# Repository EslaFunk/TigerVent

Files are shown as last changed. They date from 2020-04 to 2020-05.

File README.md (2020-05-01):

# TigerVent #
## A Ventilator design inspired by Rice University's ApolloBMV with added Alarming and Pressure Sensing

Custom Enhancements from base ApolloBMV Design:
* Honeywell NSCDRRN001PDUNV Pressure Sensor integrated with driver (still available pressure sensor)
* Assist control mode that triggers the ventilator when negative pressure (a breath) is initiated
* Alarm/Buzzer and code to handle alarms based on pressure (WIP)
* Schematic and Board files for printed circuit board designed in EAGLE (confirmed tested and working)
* updated CAD file of chassis to fit PCB and CAD file of PCB
* alternate LCD driver implementation for more available 2004 LCD Screen
* Powershell script to automate updating library in seperate folder while also maintaining git capability

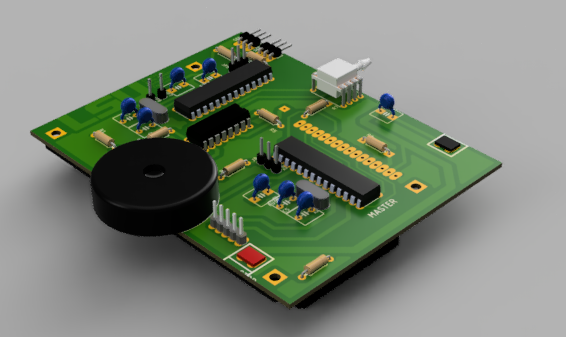
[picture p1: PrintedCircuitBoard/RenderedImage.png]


WARNING: This product is not yet approved by any regulatory agency. Please consult with a medical professional prior to use, and use at your own risk.

Special thanks to the team at Rice University for the base design. Hopefully these enhancements can provide more functionality and safety to others looking to implement these ventilators.

[renderedpcb]: https://github.com/kebroad/TigerVent/blob/master/PrintedCircuitBoard/RenderedImage.png

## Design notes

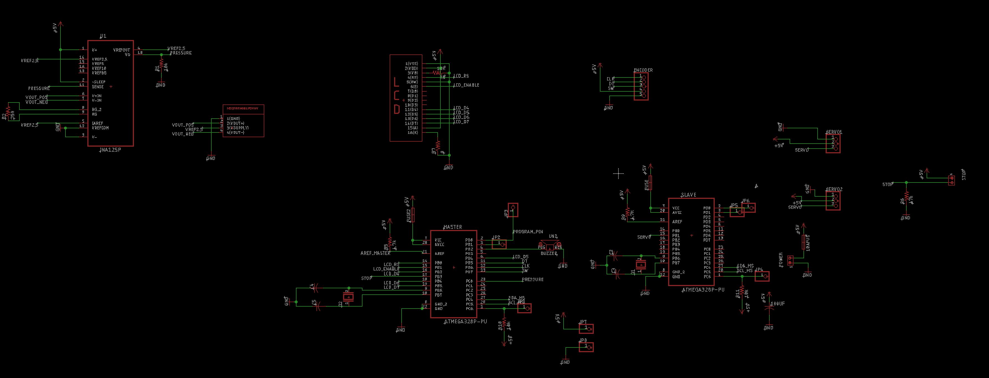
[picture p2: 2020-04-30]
PrintedCircuitBoard/schematic.jpg

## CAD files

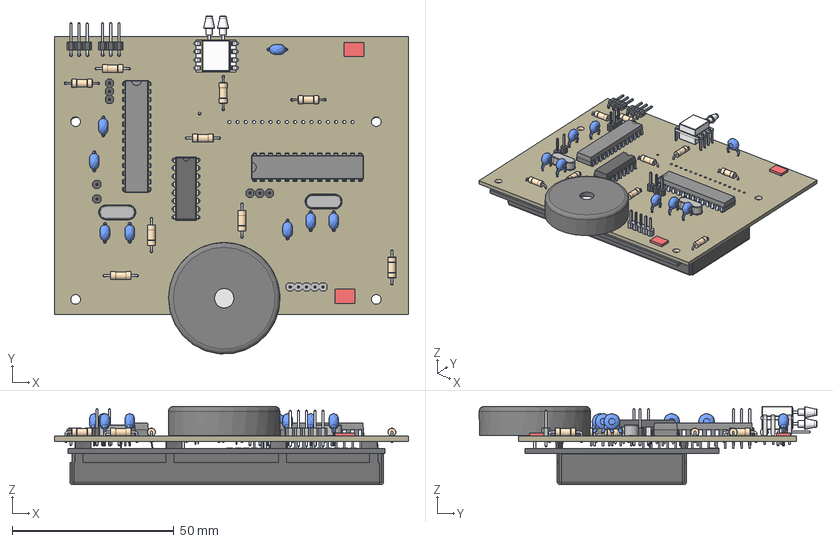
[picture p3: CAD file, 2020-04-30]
PrintedCircuitBoard/PCB.step
109.5 x 104.4 x 24.2 mm
Board
C050-075X075 x 8
ATMEGA328P-PU x 2
QS x 2
LCD
BUZZER
1X05
INA125P
4.7k x 9
1X03/90 x 2
1X01 x 8
DIP8-WIDE
1X2MTA x 2

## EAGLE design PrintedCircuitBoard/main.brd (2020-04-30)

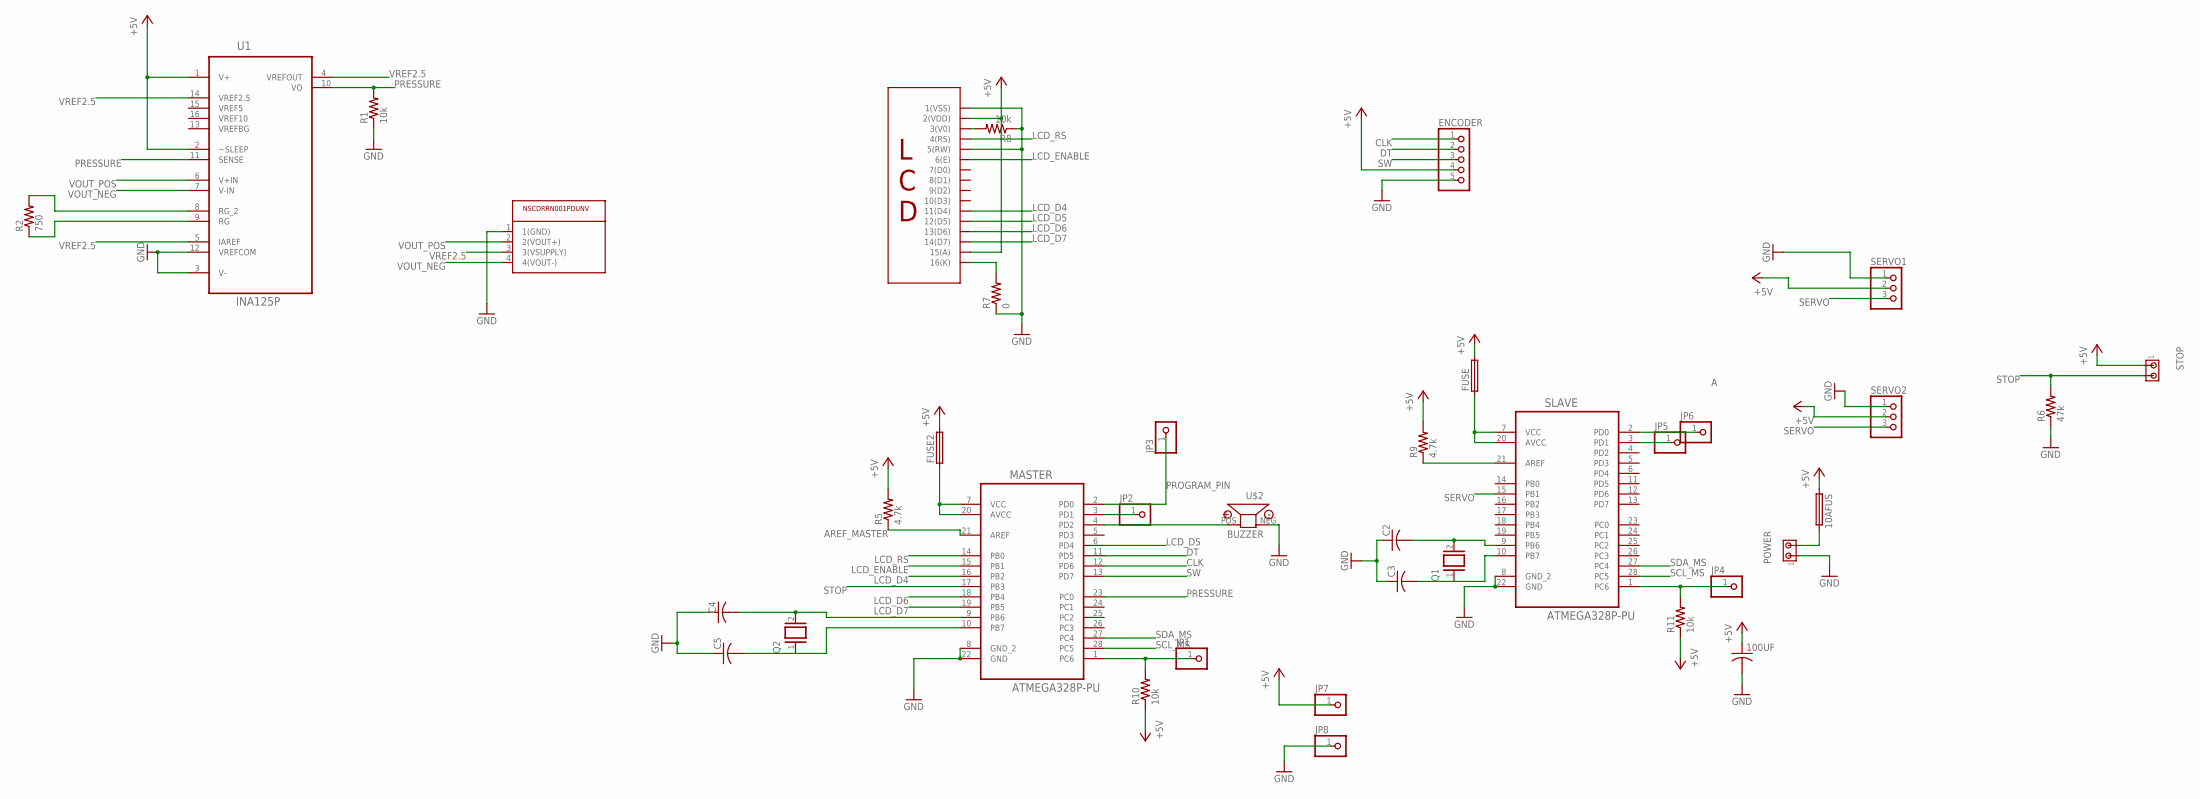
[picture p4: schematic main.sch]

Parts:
10AFUS: FUSE050-075X075; C050-075X075
100UF: 5MM_CAPACITOR050-075X075; C050-075X075
C2, C3, C4, C5: 5MM_CAPACITOR050-075X075; C050-075X075
ENCODER: PINHD-1X5; 1X05
FUSE, FUSE2: FUSE050-075X075; C050-075X075
JP1, JP2, JP3, JP4, JP5, JP6, JP7, JP8: PINHD-1X1; 1X01
MASTER: ATMEGA328P-PU; DIP254P762X457-28
POWER: MTA02-156; 1X2MTA
Q1, Q2: XTAL/S; QS
R1, R8, R10, R11: 10k; 0207/10
R2: 750; 0207/10
R5, R9: 4.7k; 0207/10
R6: 47k; 0207/10
R7: 0; 0207/10
SERVO1, SERVO2: PINHD-1X3/90; 1X03/90
SLAVE: ATMEGA328P-PU; DIP254P762X457-28
STOP: MTA02-156; 1X2MTA
U1: INA125P; DIP254P762X508-16
U$1: LCD; 1X16
U$2: BUZZER
U$3: PRESSURE_SENSOR; DIP8-WIDE

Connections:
+5V: 10AFUS.1, 100UF.1, ENCODER.4, FUSE.2, FUSE2.2, JP7.1, R5.2, R9.2, R10.1, R11.1, SERVO1.2, SERVO2.2, STOP.1, U1.1 (V+), U1.2 (~SLEEP), U$1.2 (2(VDD)), U$1.15 (15(A))
A: JP6.1, SLAVE.2 (PD0)
AREF_MASTER: MASTER.21 (AREF), R5.1
CLK: ENCODER.1, MASTER.12 (PD6)
DT: ENCODER.2, MASTER.11 (PD5)
GND: 100UF.2, C2.1, C3.1, C4.1, C5.1, ENCODER.5, JP8.1, MASTER.8 (GND_2), MASTER.22 (GND), POWER.1, R1.1, R6.1, R7.1, R8.1, SERVO1.1, SERVO2.1, SLAVE.8 (GND_2), SLAVE.22 (GND), U1.3 (V-), U1.12 (VREFCOM), U$1.1 (1(VSS)), U$1.5 (5(RW)), U$2.NEG, U$3.1 (1(GND))
LCD_D4: MASTER.16 (PB2), U$1.11 (11(D4))
LCD_D5: MASTER.6 (PD4), U$1.12 (12(D5))
LCD_D6: MASTER.18 (PB4), U$1.13 (13(D6))
LCD_D7: MASTER.19 (PB5), U$1.14 (14(D7))
LCD_ENABLE: MASTER.15 (PB1), U$1.6 (6(E))
LCD_RS: MASTER.14 (PB0), U$1.4 (4(RS))
unnamed: JP2.1, MASTER.3 (PD1)
unnamed: FUSE2.1, MASTER.7 (VCC), MASTER.20 (AVCC)
unnamed: FUSE.1, SLAVE.7 (VCC), SLAVE.20 (AVCC)
unnamed: 10AFUS.2, POWER.2
unnamed: R2.2, U1.8 (RG_2)
unnamed: C2.2, Q1.2, SLAVE.9 (PB6)
unnamed: C3.2, Q1.1, SLAVE.10 (PB7)
unnamed: JP1.1, MASTER.1 (PC6), R10.2
unnamed: JP4.1, R11.2, SLAVE.1 (PC6)
unnamed: C4.2, MASTER.9 (PB6), Q2.2
unnamed: JP5.1, SLAVE.3 (PD1)
unnamed: MASTER.4 (PD2), U$2.POS
unnamed: C5.2, MASTER.10 (PB7), Q2.1
unnamed: R7.2, U$1.16 (16(K))
unnamed: R8.2, U$1.3 (3(V0))
unnamed: R2.1, U1.9 (RG)
unnamed: R9.1, SLAVE.21 (AREF)
PRESSURE: MASTER.23 (PC0), R1.2, U1.10 (VO), U1.11 (SENSE)
PROGRAM_PIN: JP3.1, MASTER.2 (PD0)
SCL_MS: MASTER.28 (PC5), SLAVE.28 (PC5)
SDA_MS: MASTER.27 (PC4), SLAVE.27 (PC4)
SERVO: SERVO1.3, SERVO2.3, SLAVE.15 (PB1)
STOP: MASTER.17 (PB3), R6.2, STOP.2
SW: ENCODER.3, MASTER.13 (PD7)
VOUT_NEG: U1.7 (V-IN), U$3.4 (4(VOUT-))
VOUT_POS: U1.6 (V+IN), U$3.2 (2(VOUT+))
VREF2.5: U1.4 (VREFOUT), U1.5 (IAREF), U1.14 (VREF2.5), U$3.3 (3(VSUPPLY))
VREF5: U1.15 (VREF5)
VREF10: U1.16 (VREF10)
VREFBG: U1.13 (VREFBG)

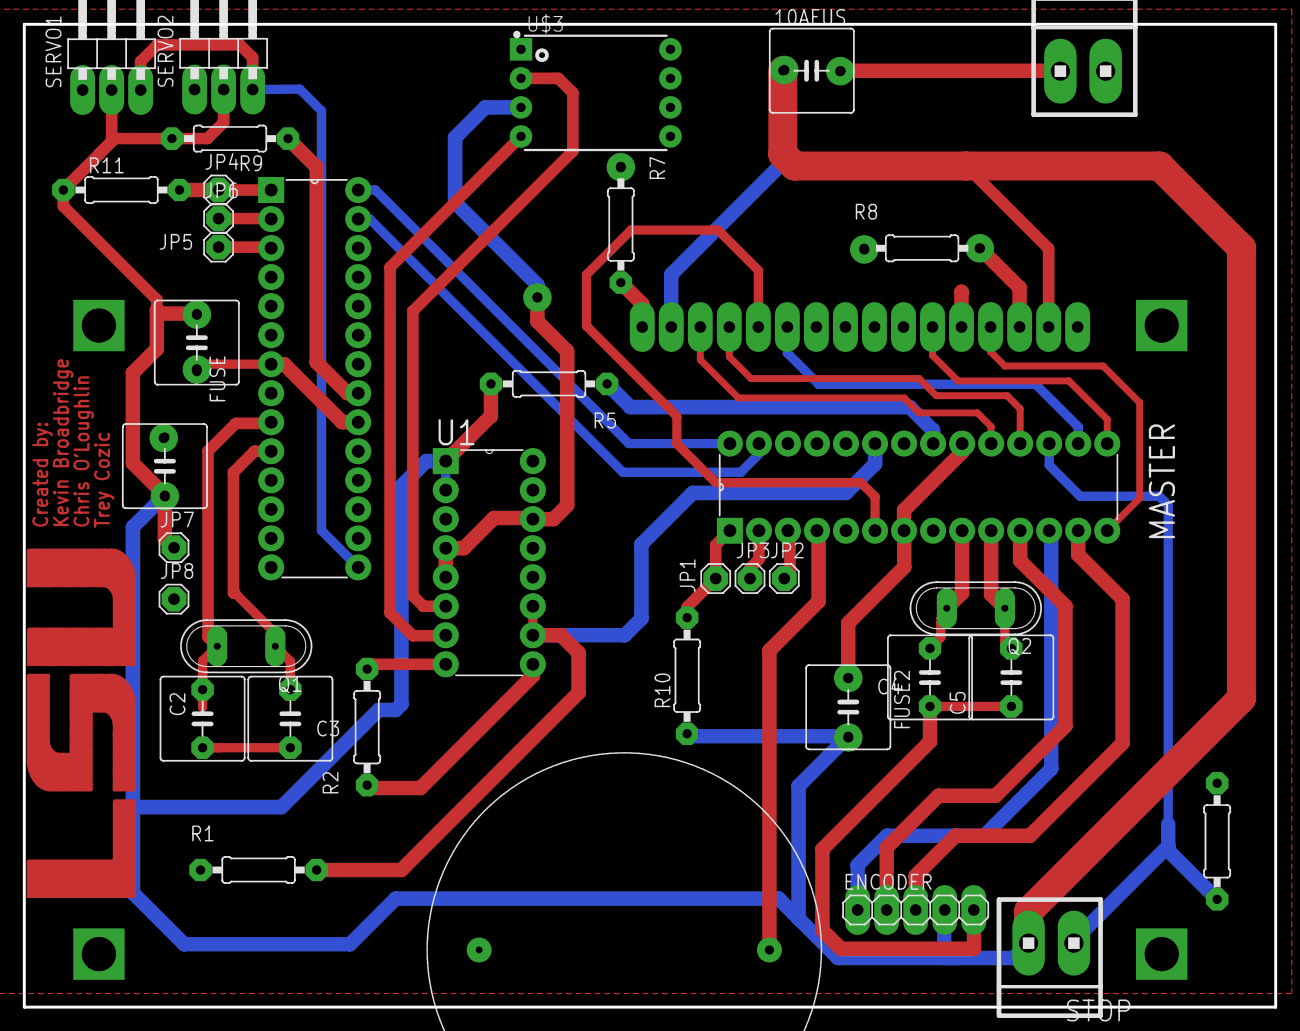
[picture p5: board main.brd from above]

Board: 2 copper layers, 109.5 x 86.0 mm, 38 parts (1 on the bottom side), 39 nets.

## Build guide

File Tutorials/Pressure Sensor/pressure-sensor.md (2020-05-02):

### Pressure Sensor:

For our pressure sensor, we decided to get the Honeywell NSCDRRN001PDUNV. This pressure sensor has a +-1 PSI range, which is +-70.307cm H2O. This is within range of the generally accepted maximum allowed 40 cm H20. This is a differential pressure sensor with two pressure inputs. The top port (port 1) is connected to the Ambu bag, and the bottom port (port 2) is left open to the atmosphere. This allows for the pressure to always be consistent. 

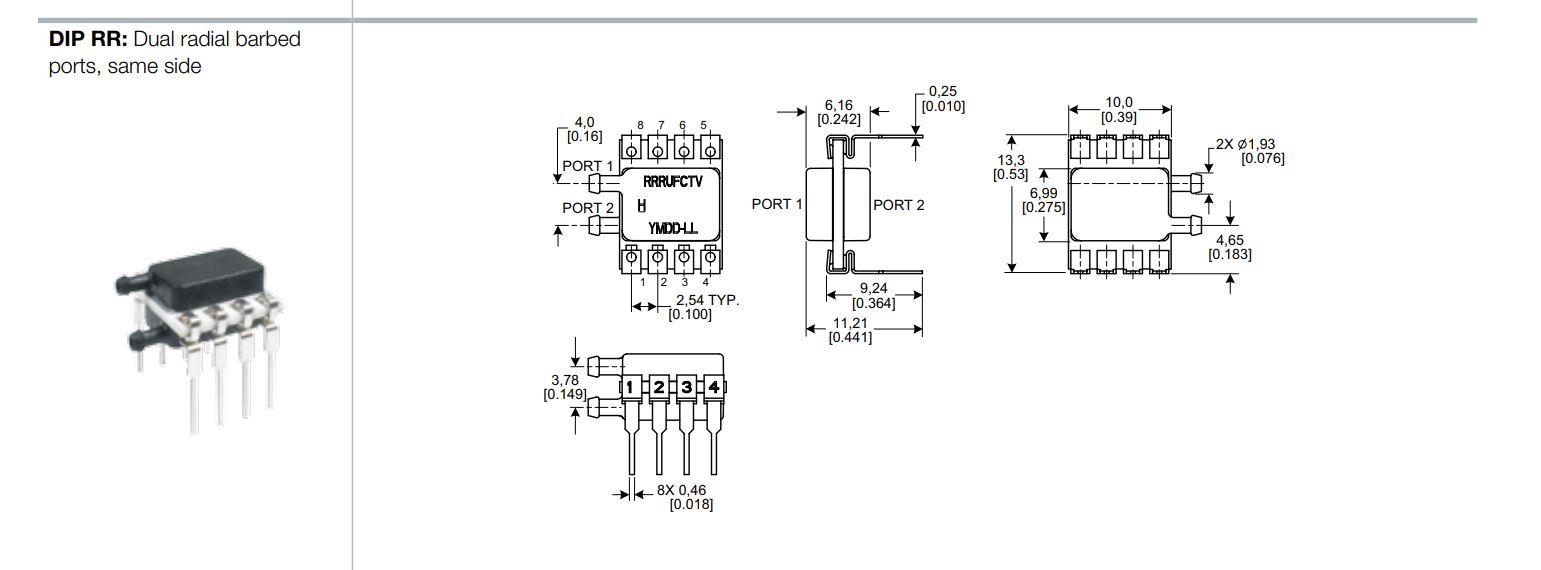
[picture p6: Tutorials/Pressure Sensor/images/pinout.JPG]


The pressure sensor part was created and is available in our eagle PCB library.

Here is our plumbing connection configuration:



We want the microcontroller to see the difference in pressure, or **Pressure Port 1 - Pressure Port 2**. This pressure sensor is an **unamplified** sensor, and has a range of about ~65mV. In order to provide an input of ~0-5V analog voltage to the microcontroller, we had to both amplify the signal while keeping the negative half of the range. We used the INA125 from TI to amplify the change in signal while maintaining its ~0-5V range by using the "psuedoground" of the 2.5V. Note that our actual circuit schematic differs slightly from this application circuit from the IINA125 datasheet.
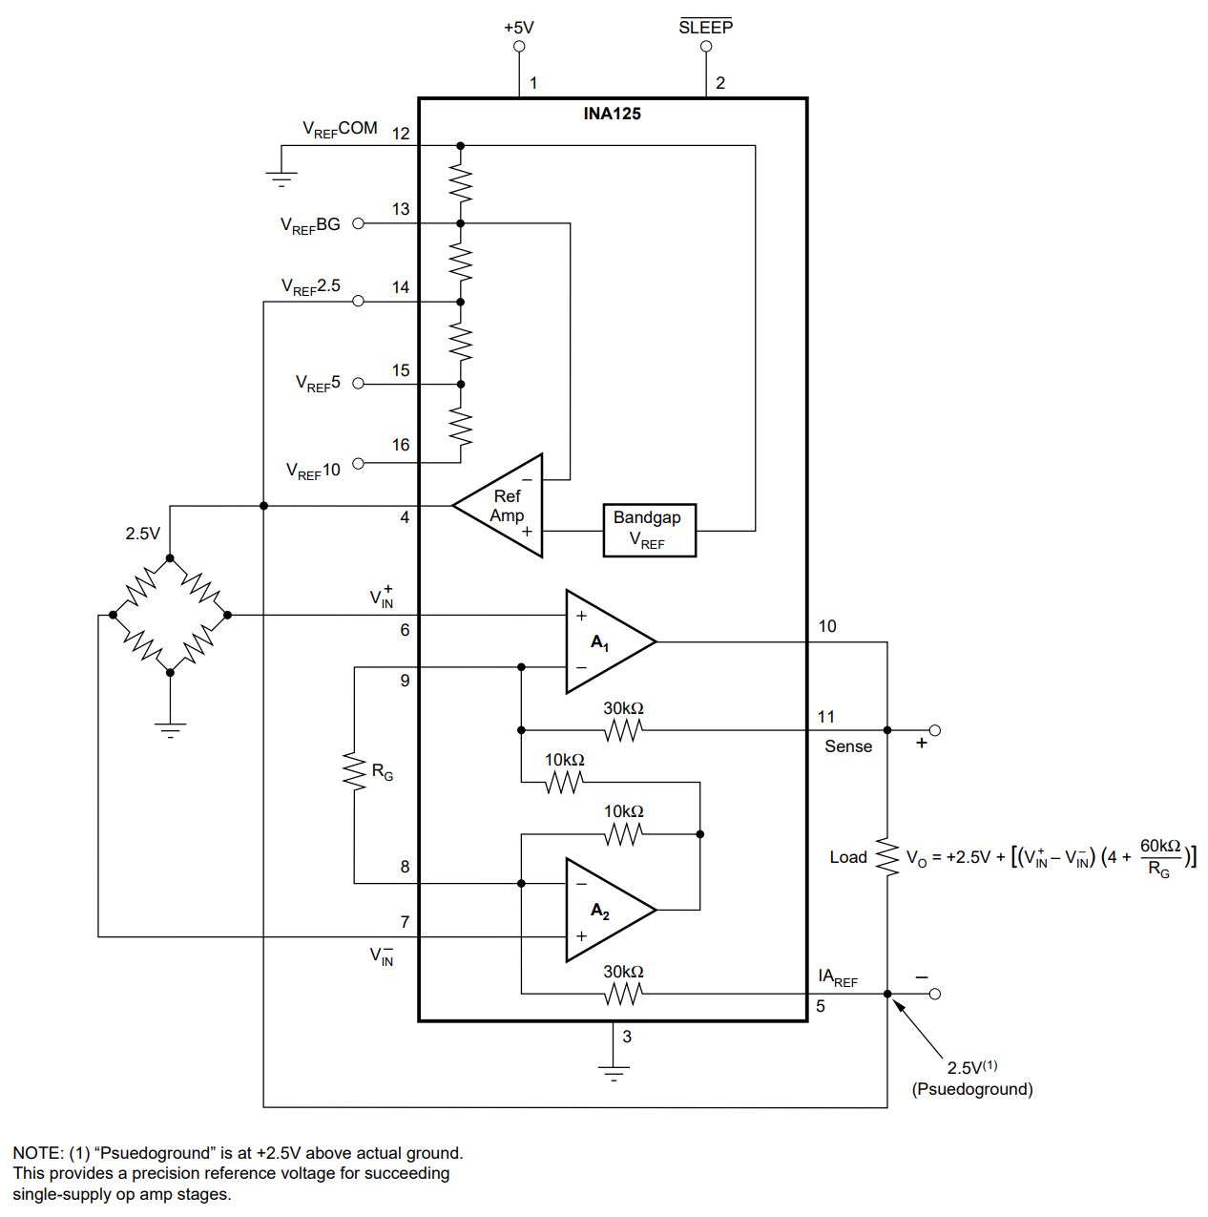
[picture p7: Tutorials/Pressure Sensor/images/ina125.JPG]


From the gain measurements and equation, we decided on a gain resistor (Rg) to be 750 Ohms. We were able to get a voltage range of ~0-4V from this configuration, going into the microcontroller, where ~2V is where both pressure ports have the same pressure.

In the code, we were able to adjust the voltage to cm H20 by finding the multiplier and constant (Pressure (cm H2O) = multiplier * Input (V) + Constant) and got the multiplier by the max/min in pressure range (|+-1| = 2 PSI or |+-70.307| = 140.614 cmH2O) over the max/min in the voltage range (~4V - 0 V) and, once getting the multiplier, got the constant offset by substituting one of the ends of the range into the equation. You will need to tweak these values based on the gain resistor you use and comparison with a pre-calibrated pressure sensor system.

[pinout]: https://github.com/kebroad/TigerVent/blob/master/Tutorials/Pressure%20Sensor/images/pinout.JPG

[plumbingconfig]: https://github.com/kebroad/TigerVent/blob/master/Tutorials/Pressure%20Sensor/images/plumbingconfig.jpg

[ina125]: https://github.com/kebroad/TigerVent/blob/master/Tutorials/Pressure%20Sensor/images/ina125.JPG

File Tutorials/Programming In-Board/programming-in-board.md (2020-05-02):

### Programming In-Board

In order to successfully upload the sketches, you must first bootload the ATMega328. Instructions here:
https://www.arduino.cc/en/Tutorial/ArduinoToBreadboard

Here is the schematic from Arduino illustrates how to connect to an Arduino on a breadboard:

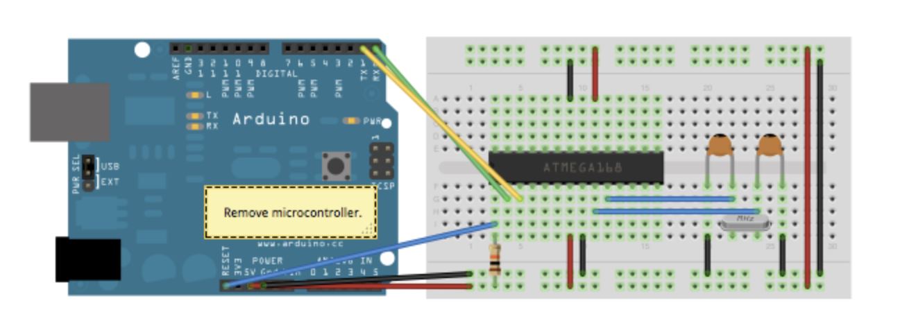
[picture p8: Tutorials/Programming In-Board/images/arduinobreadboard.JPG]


There are 5 pins that need to be connected to the ATMega328 in order to program it. They are:

 * 5V (Red wires)
 * GND (Black wires)
 * TX (yellow wire)
 * RX (green wire)
 * RESET (Blue wire)

This was incorporated into the PCB design to allow in-board programming, after the microcontroller was placed into the socket. Here's an illustration of what it looks like on our schematic and board:

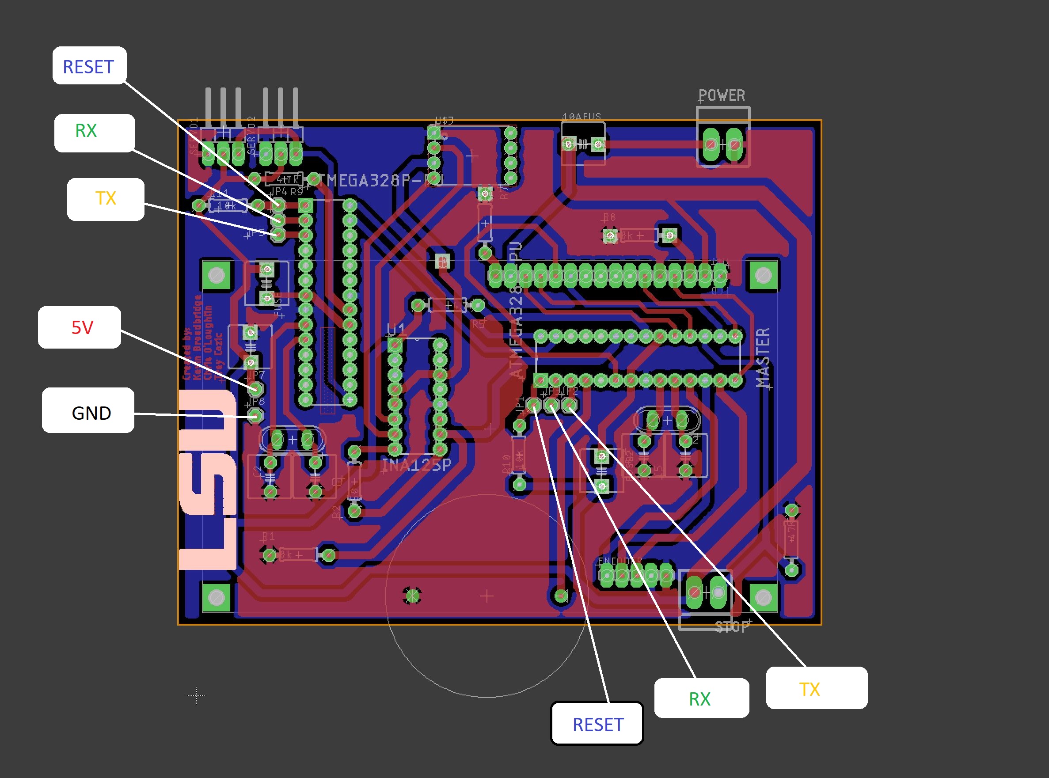
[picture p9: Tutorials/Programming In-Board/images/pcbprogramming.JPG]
 

We used female sockets to program the chips on the fly. The IC on the left is the IC for the slave and the IC on the right is the master. For both, 5V and GND needs to be connected, but depending on which one you want to program, the other 3 wires should be in their respective connectors.

All credit of Arduino images belongs to Arduino.

[arduinobreadboard]: https://github.com/kebroad/TigerVent/blob/master/Tutorials/Programming%20In-Board/images/arduinobreadboard.JPG

[pcbprogramming]: https://github.com/kebroad/TigerVent/blob/master/Tutorials/Programming%20In-Board/images/pcbprogramming.JPG

[actualboard]: https://github.com/kebroad/TigerVent/blob/master/Tutorials/Programming%20In-Board/images/actualboard.jpg

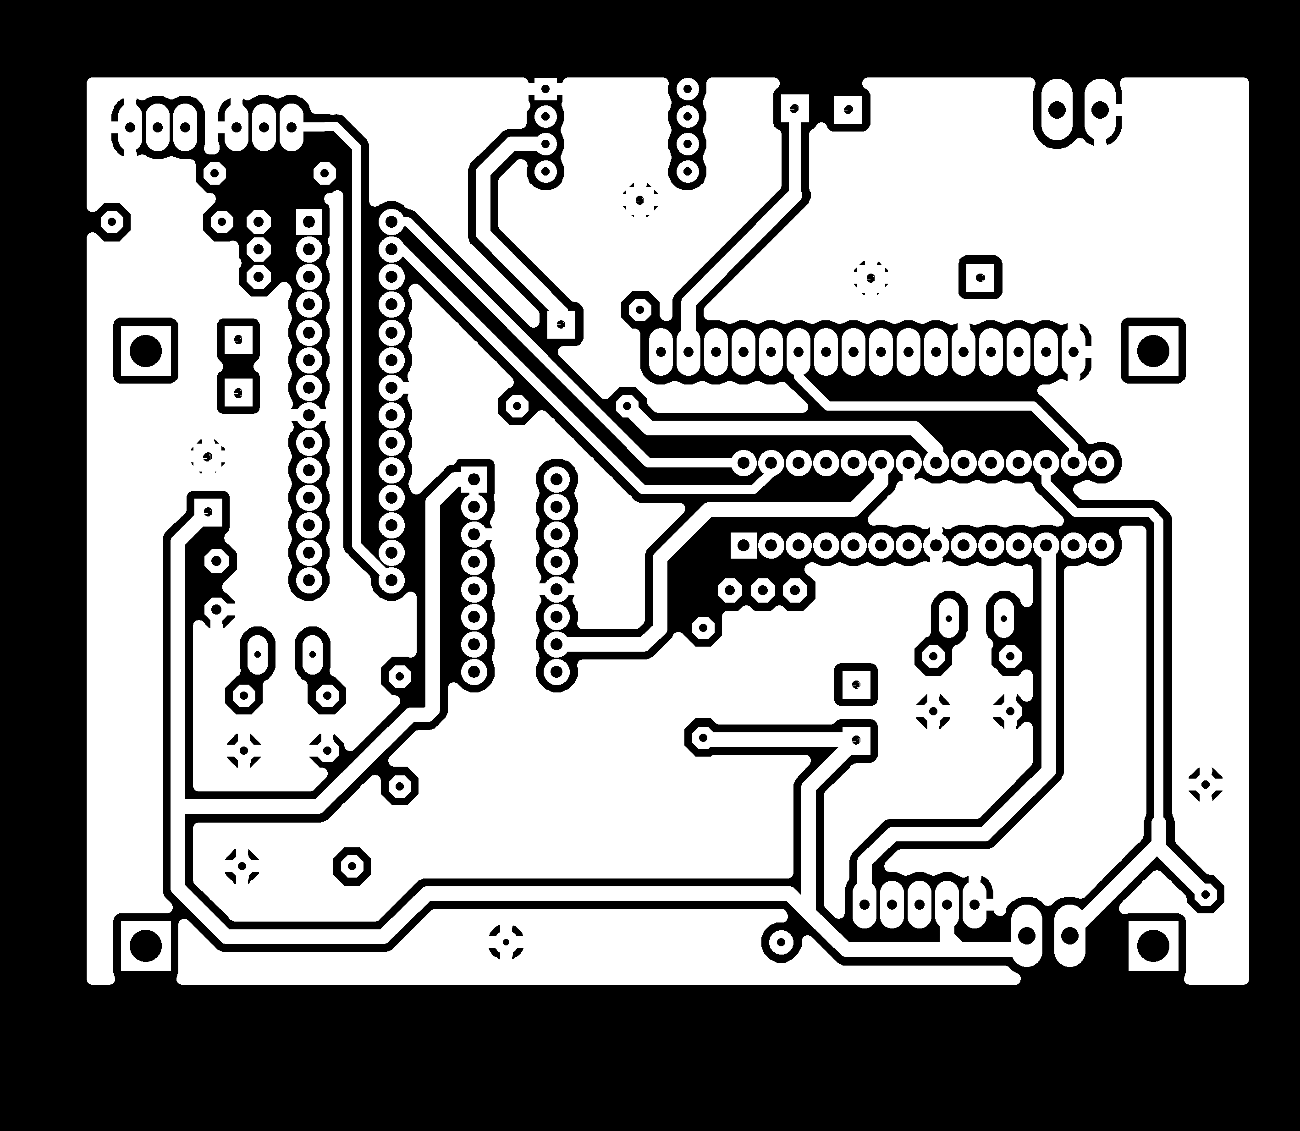
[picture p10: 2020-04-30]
PrintedCircuitBoard/main.sol.bmp

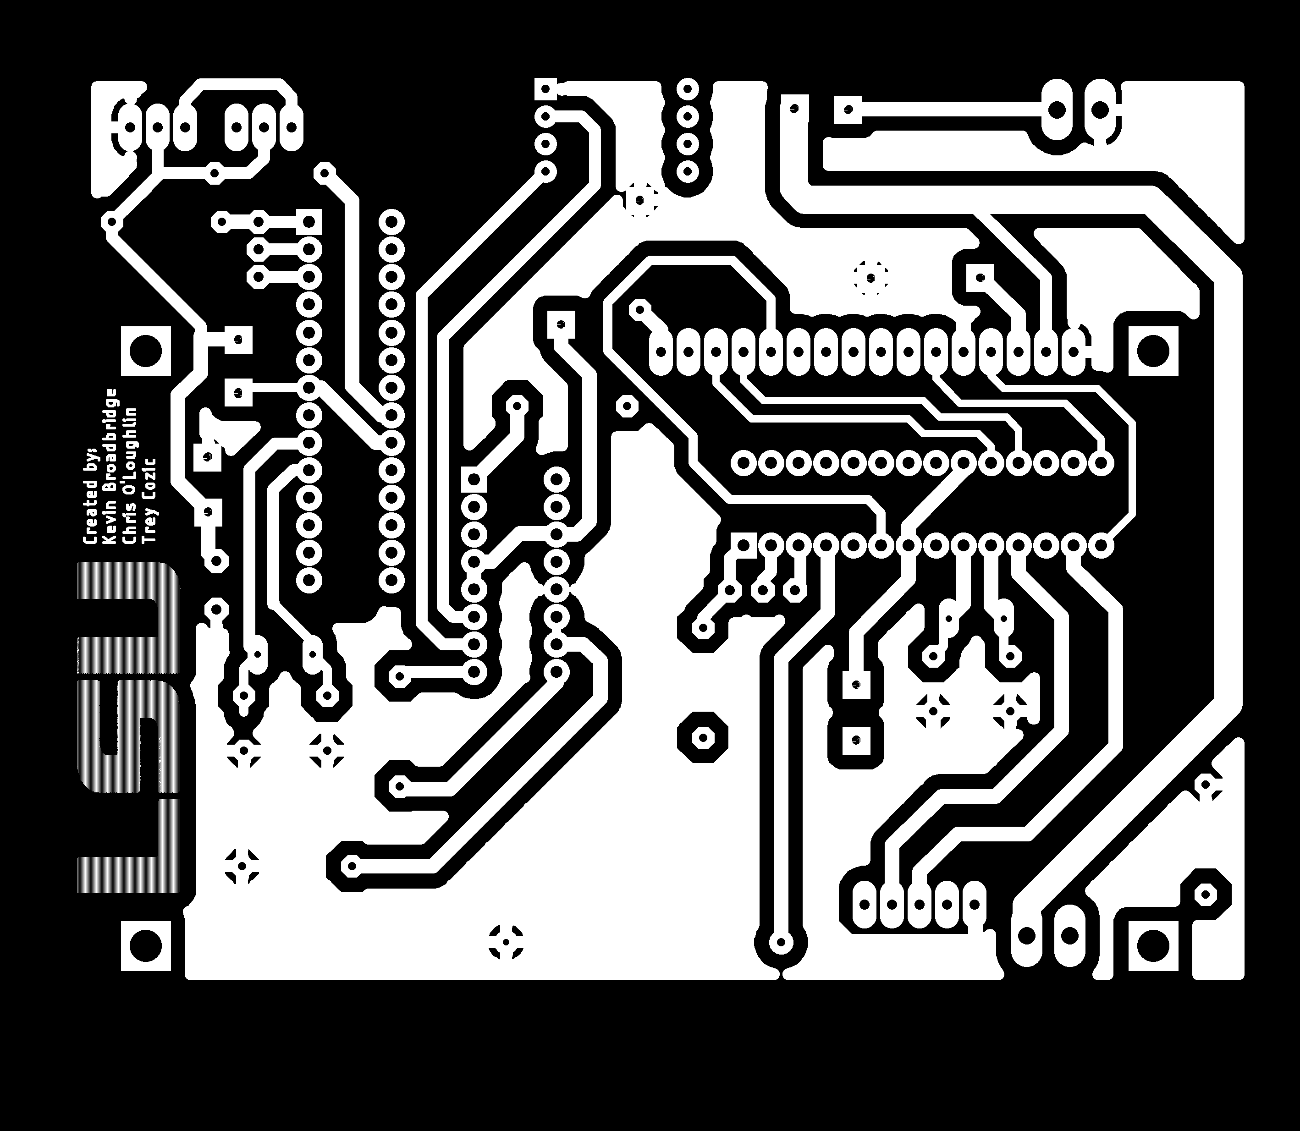
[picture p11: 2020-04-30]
PrintedCircuitBoard/main.cmp.bmp

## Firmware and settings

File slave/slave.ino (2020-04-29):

#include <Wire.h>
#include <Servo.h>
#include <trajfactory.h>

// Address of slave.
#define SLAVE_ADDR 8

// Pin definitions.
#define SERVO_PIN 9

// Limits of servo.
#define SERVO_MIN 2400
#define SERVO_MAX 550

// Init trajectory generation and current pointer.
TrajFactory tf = TrajFactory();
Trajectory* traj_ptr = 0;

// Init servo class.
Servo servo;

// Init current ventilator params.
int rr;
float ie;
int setpoint;
float hold;
int delta_t;
char state;

void setup() {

  // Join i2c bus with address SLAVE_ADDR.
  Wire.begin(SLAVE_ADDR);

  // Register callback function for i2c receive.
  Wire.onReceive(recieveTraj);

  // Start serial output for trajectory monitoring.
  Serial.begin(9600);

  // Attach servo.
  servo.attach(SERVO_PIN);

  // Set state to off.
  state = 'X';
}

void loop() {
  // Run device in different modes.
  switch (state) {
    // immediate assist, push all the way with the current config, then continue as normal



    // Device is on, continue following trajectory.

    case 'O': 
      moveTo(traj_ptr->nextStep(), traj_ptr->getDeltaTime());
      //delay(100);
      break;
    

    // Device has been instructed to shutdown.
    case 'X':
      stop();
      break;


    // Device has recieved a new trajectory, load and start.
    case 'L':

      // Stop motion.
      stop();

      // If assigned ptr, delete contents
      if (traj_ptr != 0) {
        delete traj_ptr;
      }

      // Build new trajectory
      traj_ptr = tf.build(rr, ie, setpoint, hold, delta_t);

      // Set device on.
      state = 'O';
      break;
    
    case 'A':
        int cur_pos = traj_ptr->nextStep();
                 // Serial.println("-------");
        //Serial.println("cur_pos");
        //Serial.println(cur_pos);
        
        int next_pos;
        do{
          next_pos = traj_ptr->nextStep();
          //Serial.println("next_pos");
          //Serial.println(next_pos);
          //Serial.println("-------");
        } while((next_pos < cur_pos));
        moveTo(next_pos, traj_ptr->getDeltaTime());
        /*
      //skip all decreasing movements, get to the next push in movement
        int cur_pos;
        int next_pos = traj_ptr->nextStep();
        do{
          cur_pos = next_pos;
          next_pos = traj_ptr->nextStep();
        }while(cur_pos > next_pos);
       */
      //moveTo(SERVO_MIN+1, 1000);
      state = 'O';
      break;
    //case 'A':
      //stop();
      //break;

      /*
      int cur_pos = traj_ptr->nextStep();
      while(cur_pos > traj_ptr->nextStep() ){
        cur_pos = traj_ptr->nextStep();
      }
            break;
                  moveTo(traj_ptr->nextStep(), traj_ptr->getDeltaTime());
                  */



    
    /*
      //skip all decreasing movements, get to the next push in movement
      int cur_pos = traj_ptr->nextStep();
     while(cur_pos > traj_ptr->nextStep() ){
        cur_pos = traj_ptr->nextStep();
     }
     state = 'O';
     */
  }
}

void moveTo(int pos, int delta_t){

  // Write current position instruction to console.
  Serial.println(pos);

  // Move the servos to next setpoint and wait delta time.
  servo.writeMicroseconds(SERVO_MIN-pos);
  delay(delta_t);
}

void stop(){

  // If we have already generated a trajectory, follow it till the end.
  if (traj_ptr != 0) {
    while (traj_ptr->getCurrentStep() != 0) {
      moveTo(traj_ptr->nextStep(), traj_ptr->getDeltaTime());
    }
  // If not, got to 0 position.
  } else {
    moveTo(0, 100);
  }
}

void recieveTraj(int num_entries) {

  // Read the state from incoming transmission.
  char recieved_state = Wire.read();

  // Either change machine state or load new settings.
  switch (recieved_state) {
    case 'X':
      state = 'X';
      break;
    case 'A':
      state = 'A';
      break;
    case 'L':
      state = 'L';


      // Load new params
      byte high = Wire.read();
      byte low = Wire.read();
      setpoint = (high << 8) | low;

      rr = Wire.read();

      byte inhale = Wire.read();
      byte exhale = Wire.read();
      ie = float(inhale) / exhale;

      byte hold_s = Wire.read();
      byte hold_dec = Wire.read();
      hold = hold_s + hold_dec/100.0;

      delta_t = Wire.read();

      break;
  }
}

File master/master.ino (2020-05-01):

#include "panel.h"
#include "Wire.h"
#include "buzzer.h"
#include "nscdrrn001pdunv.h"

// Address of slave.
#define SLAVE_ADDR 8

// Pin definitions.
#define DISPLAY_PIN 3
#define ENC_CLK_PIN 6
#define ENC_DT_PIN 5
#define ENC_BUTTON_PIN 7
#define STOP_BUTTON_PIN 11
#define PRESSURE_SENSOR_PIN A0
#define BUZZER_PIN 2
#define PRESSURE_CONVERSION_MULTIPLIER 0.169618
#define PRESSURE_CONVERSTION_CONSTANT -71.3247129


Buzzer buzzer(BUZZER_PIN);
// Init peripherals.
Nscdrrn001pdunv pressure_sensor(PRESSURE_SENSOR_PIN, PRESSURE_CONVERSION_MULTIPLIER, PRESSURE_CONVERSTION_CONSTANT);
Lcd2004 display(DISPLAY_PIN);
Encoder enc(ENC_DT_PIN, ENC_CLK_PIN);
ButtonManager encoder_button(ENC_BUTTON_PIN, true);
ButtonManager stop_button(STOP_BUTTON_PIN, false);

// Default settings.
VentSettings vs = {'X', 500, 12, 1, 3, 0, 00, 20, 0, 0, 0, false, NoAlarm, VolumeControl}; 

// Default limits.
VentLimits vl;

// Calibration for TV on Ambu bag SPUR II.
int cal[9] = {950, 1062, 1155, 1238, 1320, 1393, 1465, 1538, 1610};

// String params for splash screens.
String* splash_text = new String[4];
String* warning_text = new String[4];
String* alarm_text = new String[4];

// Init panel pointers.
SplashPanel* splash_ptr;
SplashPanel* warning_ptr;
AlarmPanel* alarm_ptr;
EditPanel* start_ptr;
EditPanel* apply_ptr;
RunningPanel* run_ptr;
PausePanel* pause_ptr;

// Init display panel pointer.
Panel* cur_panel;

void setup()
{

  // Join i2c bus.
  Wire.begin();

  // Start serial debug connection.
//  Serial.begin(9600);

  // Start display.
  display.begin(9600);
  display.clearDisplay();

  // Init slash text.
  splash_text[0] = "    LSU TigerVent   ";
  splash_text[1] = "";
  splash_text[2] = "    inspired by";
  splash_text[3] = "     ApolloBVM";

  //Init warning text.
  warning_text[0] = "      WARNING: ";
  warning_text[1] = "   USE ADULT SIZED";
  warning_text[2] = "   BAG VALVE MASK";
  warning_text[3] = "";

  //Init alarm text.
  alarm_text[0] = "      ALARM: ";
  alarm_text[1] = "   OVER PRESSURE";
  alarm_text[2] = "   BAG VALVE MASK";
  alarm_text[3] = "";


  // Init panels.
  start_ptr = new EditPanel(&display, &enc, &encoder_button, &stop_button, &vs, &vl, "Confirm & Run?", &run_ptr, 0);
  warning_ptr = new SplashPanel(&display, &enc, &encoder_button, &stop_button, &vs, warning_text, 2000, &start_ptr);
  splash_ptr = new SplashPanel(&display, &enc, &encoder_button, &stop_button, &vs, splash_text, 2000, &warning_ptr);
  alarm_ptr = new AlarmPanel(&display, &enc, &encoder_button, &stop_button, &vs, &pause_ptr, &buzzer);
  apply_ptr = new EditPanel(&display, &enc, &encoder_button, &stop_button, &vs, &vl, "Apply Changes?", &run_ptr, &pause_ptr);
  run_ptr = new RunningPanel(&display, &enc, &encoder_button, &stop_button, &vs, &apply_ptr, &pause_ptr, &pressure_sensor, &alarm_ptr );
  pause_ptr = new PausePanel(&display, &enc, &encoder_button, &stop_button, &vs, &start_ptr, &run_ptr);

  // Delay just cause.
  delay(100);

  // Set current panel to splash.
  cur_panel = splash_ptr;
  cur_panel->start();

}

void loop()
{

  // //if an alarm is on, continue
  // alarmManager.update();
    
  // }
  // if(pressure_sensor.read() > 40){
  //   alarm = HighPressureAlarm;
  // }
  // Poll button status.
  encoder_button.poll();
  stop_button.poll();

  // Update current panel.
  Panel* new_panel = cur_panel->update();

  // If we get a new panel, start and switch to it.
  if (new_panel != 0) {

    cur_panel = new_panel;



        //display.clearDisplay();
    cur_panel->start();
  }

  // Transmit to the device if necessary.
  if (vs.send)
    transmit();
}

void transmit() {

  // Transmit to the slave device.
  Wire.beginTransmission(SLAVE_ADDR);

  // Write the mode first.
  Wire.write(vs.mode);

  // Send settings to controller unit, if we're loading.
  if (vs.mode == 'L') {
    // Calculate setpoint based on calibration.
    int setpoint = cal[(vs.tidal_volume - vl.min_tidal_volume)/vl.delta_tidal_volume];

    // Send the ventilation parameters to slave.
    Wire.write(byte(setpoint >> 8));
    Wire.write(byte(setpoint & 0x00FF));
    Wire.write(byte(vs.respiration_rate));
    Wire.write(byte(vs.inhale));
    Wire.write(byte(vs.exhale));
    Wire.write(byte(vs.hold_seconds));
    Wire.write(byte(vs.hold_decimals));
    Wire.write(byte(vs.delta_time));

    // Set the mode to on as device will start.
    vs.mode = 'O';
  }

  // Send i2c message.
  Wire.endTransmission();

  // Sent settings so disable send.
  vs.send = false;
}

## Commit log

2020-04-10 Completed integration with LCD2004 driver
2020-04-15 moved LCD driver to src folder
2020-04-17 added pressure sensor
2020-04-17 Changed pin for updated schematic
2020-04-17 fixed pin
2020-04-25 implemented buzzer and pressure sensor drivers
    [master.ino, panel.cpp]
2020-04-26 Implemented alarm panel and high pressure alarm
2020-04-27 Integrated modes and mode switching
2020-04-27 implemented modes and mode switching
2020-04-30 changed folder structure in Copy-ArduinoLibrary
2020-04-30 Added PCB files
    [main.brd, main.sch]
2020-04-30 added rendered image of PCB
2020-04-30 added 3d files
    [PCB.step]
2020-05-01 added CAD files in readme
2020-05-02 added programming in-board documentation
2020-05-02 updated in-socket programming
2020-05-02 updated pressure sensor documentation
2020-05-02 updated pressure sensor tutorial
